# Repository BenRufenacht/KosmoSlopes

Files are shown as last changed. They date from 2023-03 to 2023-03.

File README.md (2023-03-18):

# KosmoSlopes
 Kosmo Version of the Kassutronics Slope Module

 <p align="center">
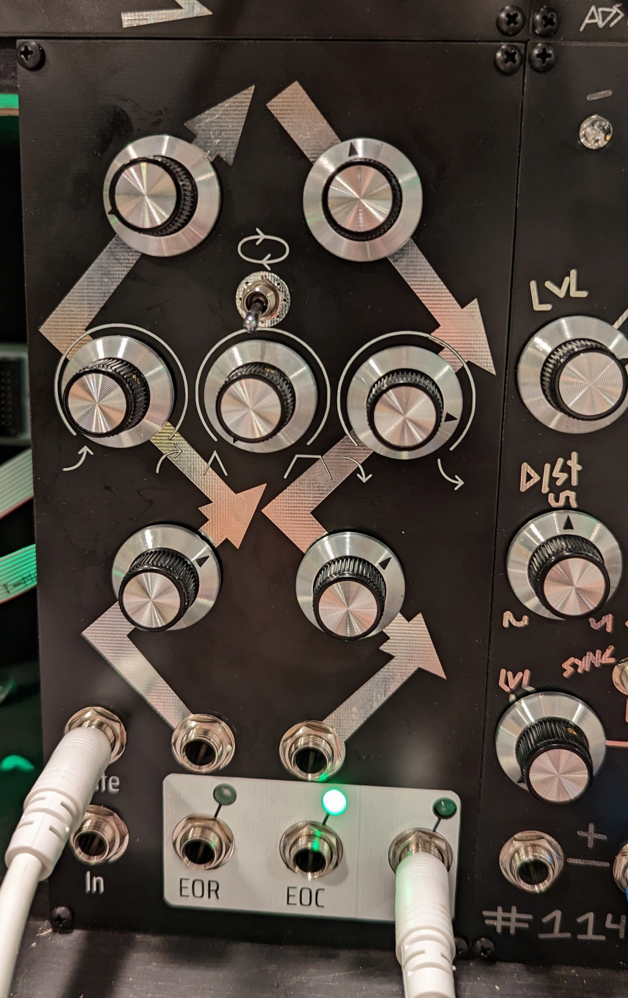
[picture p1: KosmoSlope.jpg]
Kosmo Slope
  
</p>

[Build Docs from Kassutronics](https://github.com/kassu/kassutronics/blob/master/documentation/Slope/Kassutronics_Slope_Build_Docs_2.0B.pdf)

Status:   
February 2023 - First run of manufacturing found some minor mistakes that were fixed, but the updates to the main board have not been tested.

License:  
[CC-BY-SA](https://creativecommons.org/licenses/by-sa/3.0/)

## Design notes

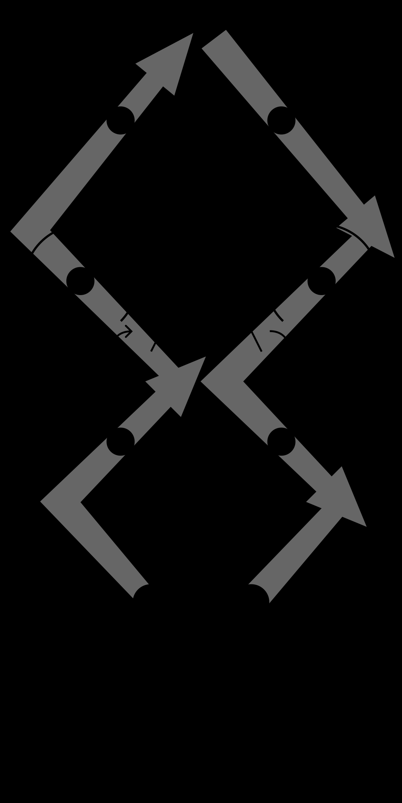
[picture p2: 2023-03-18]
SlopePanelTin.png

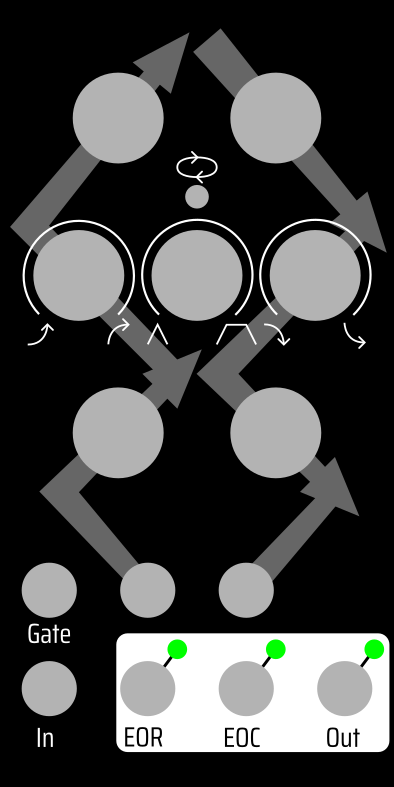
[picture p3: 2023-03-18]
SlopePanelGraphic.png

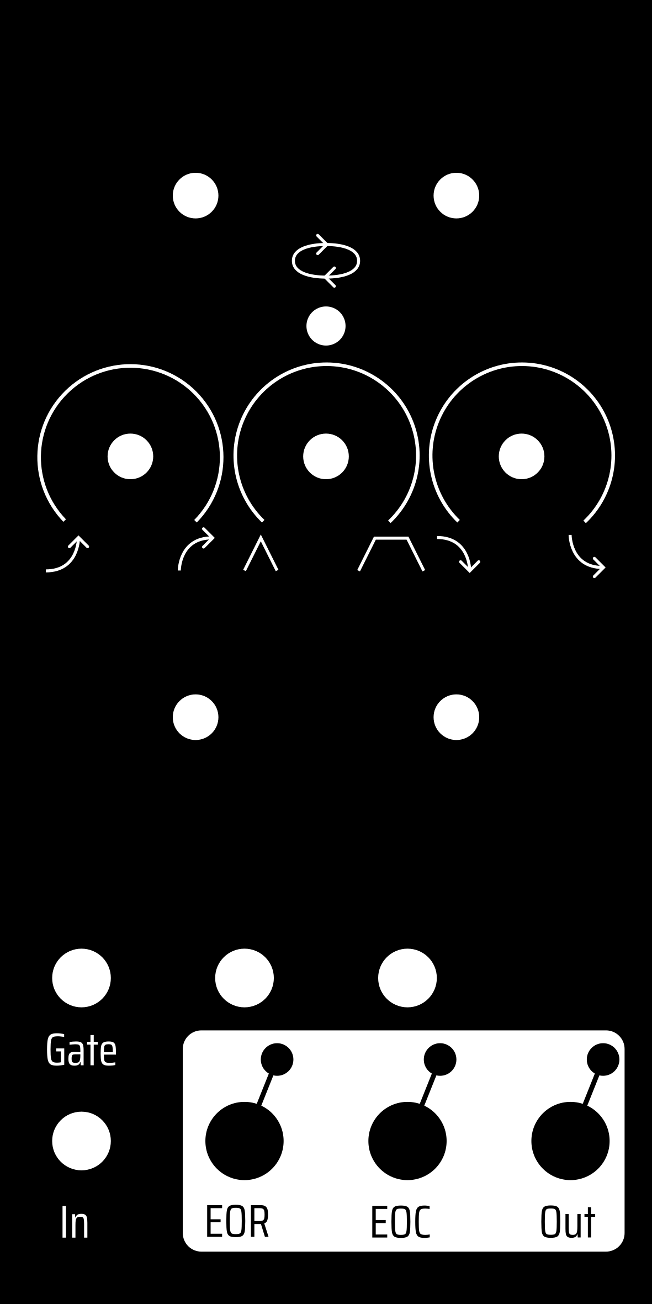
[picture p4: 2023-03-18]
SlopePanelSilk.png

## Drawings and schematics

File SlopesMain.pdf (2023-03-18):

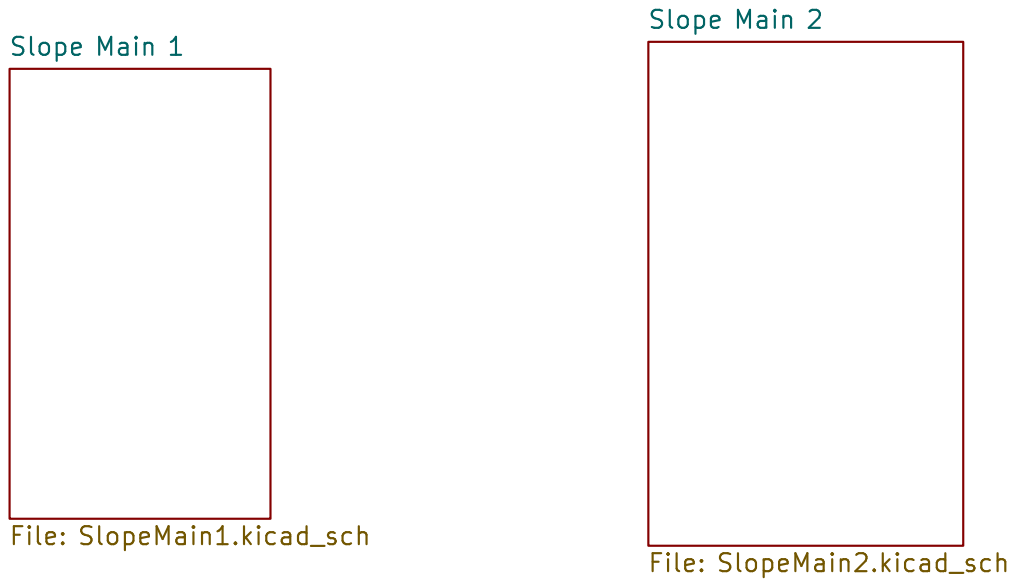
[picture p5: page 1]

File: SlopesMain.kicad_sch Sheet: /
Id: 1/3 Title: Kosmo Slopes

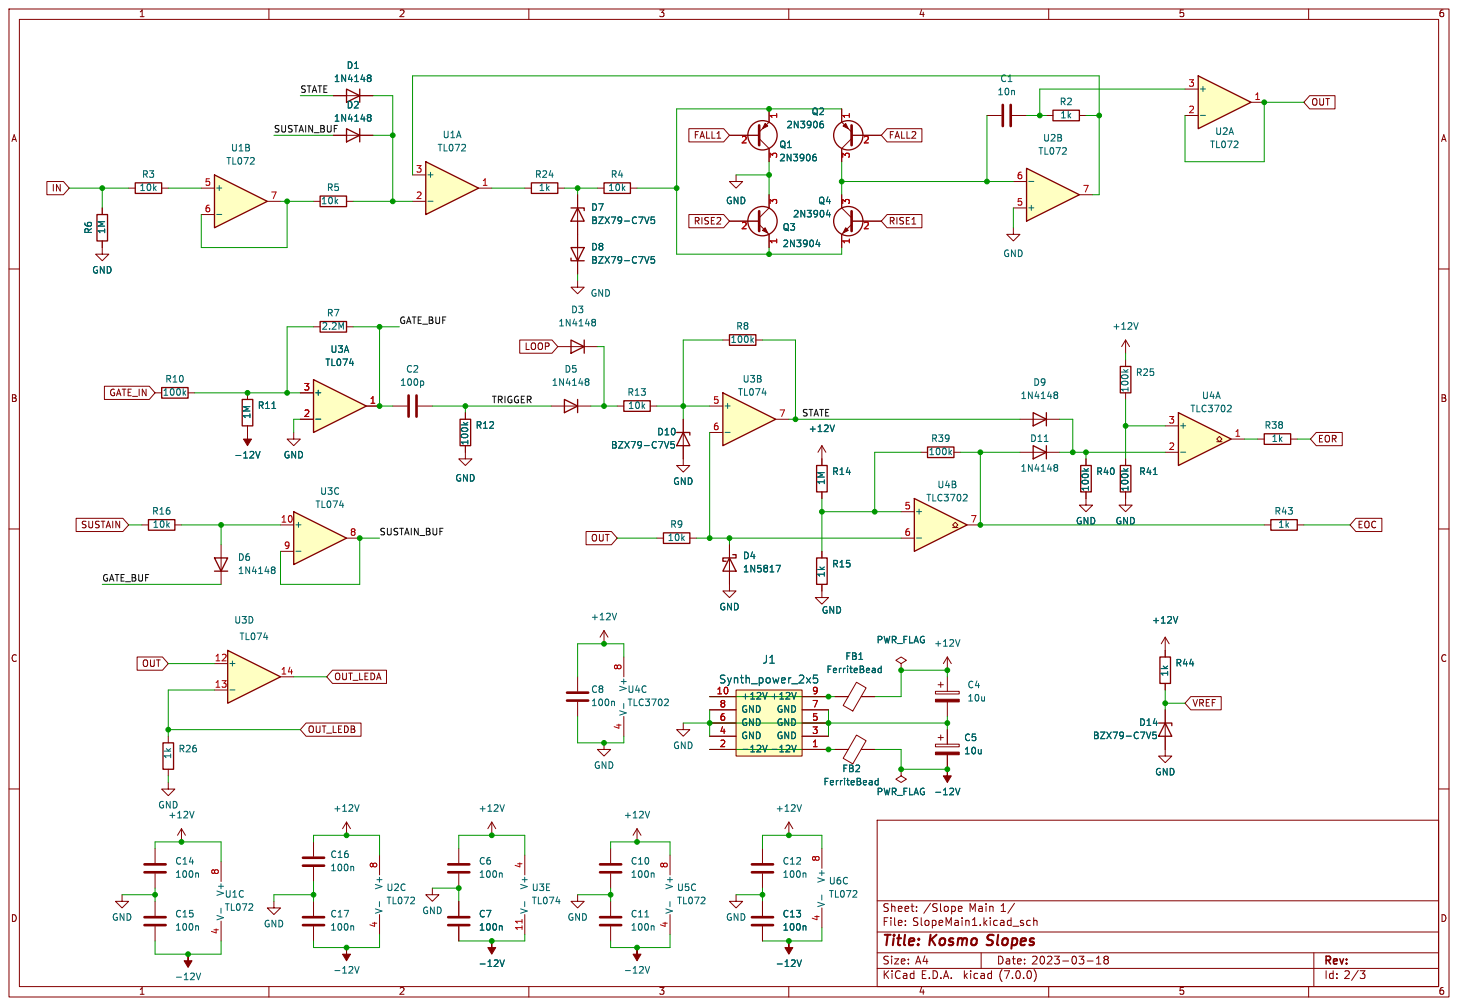
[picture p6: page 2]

Id: 2/3 Title: Kosmo Slopes

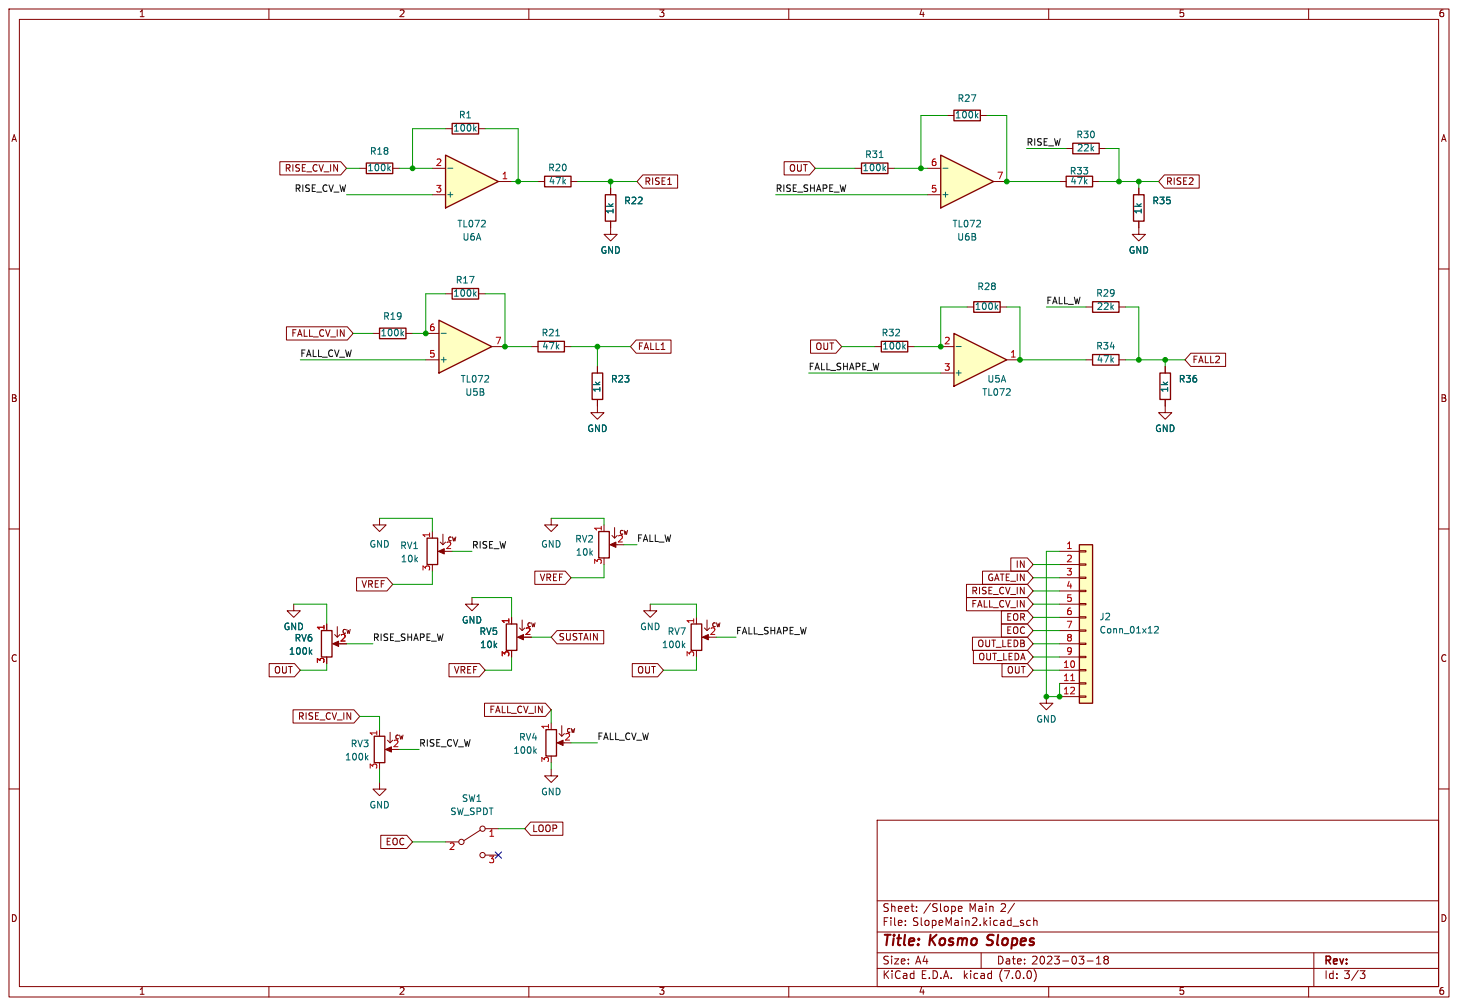
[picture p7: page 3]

Id: 3/3 Title: Kosmo Slopes

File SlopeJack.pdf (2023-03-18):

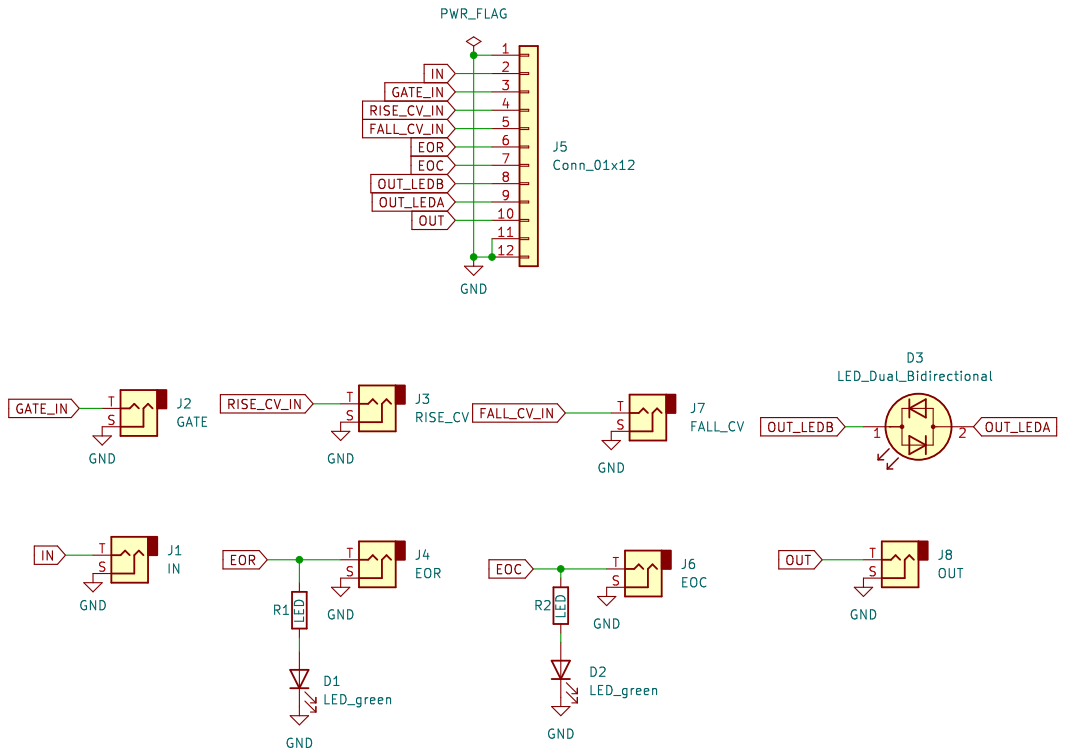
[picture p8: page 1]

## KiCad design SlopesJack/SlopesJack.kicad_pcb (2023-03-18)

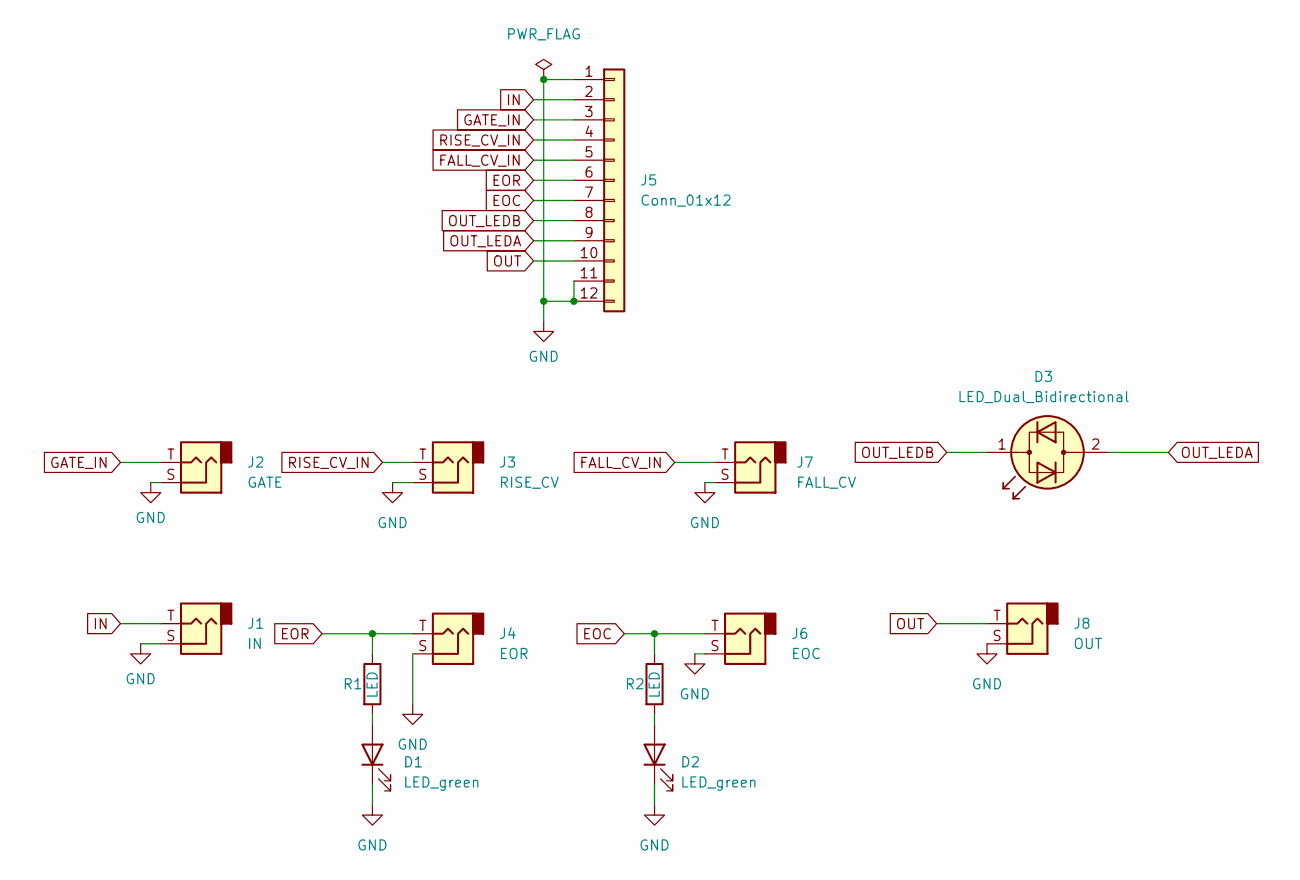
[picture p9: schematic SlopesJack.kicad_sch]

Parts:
D1, D2: LED_green; LED_D5.0mm
D3: LED_Dual_Bidirectional; LED_D5.0mm
J1: IN; Jack_6.35mm_PJ_629HAN_slots
J2: GATE; Jack_6.35mm_PJ_629HAN_slots
J3: RISE_CV; Jack_6.35mm_PJ_629HAN_slots
J4: EOR; Jack_6.35mm_PJ_629HAN_slots
J5: Conn_01x12; PinHeader_1x12_P2.54mm_Vertical
J6: EOC; Jack_6.35mm_PJ_629HAN_slots
J7: FALL_CV; Jack_6.35mm_PJ_629HAN_slots
J8: OUT; Jack_6.35mm_PJ_629HAN_slots
R1, R2: LED; R_Axial_DIN0207_L6.3mm_D2.5mm_P10.16mm_Horizontal

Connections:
EOC: J5.7, J6.T, R2.1
EOR: J4.T, J5.6, R1.1
FALL_CV_IN: J5.5, J7.T
GATE_IN: J2.T, J5.3
GND: D1.1 (K), D2.1 (K), J1.S, J2.S, J3.S, J4.S, J5.1, J5.11, J5.12, J6.S, J7.S, J8.S
IN: J1.T, J5.2
unnamed: D1.2 (A), R1.2
unnamed: D2.2 (A), R2.2
OUT: J5.10, J8.T
OUT_LEDA: D3.2 (AK), J5.9
OUT_LEDB: D3.1 (KA), J5.8
RISE_CV_IN: J3.T, J5.4

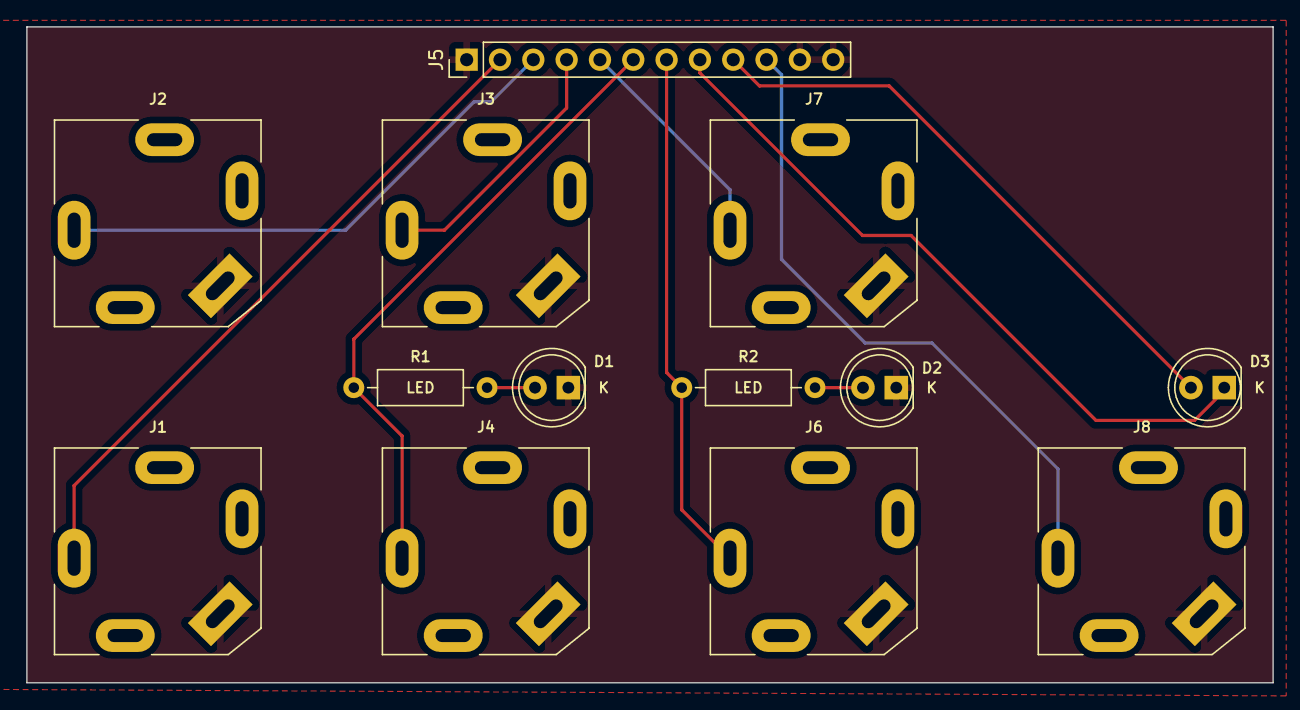
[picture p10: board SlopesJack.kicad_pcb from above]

Board: 2 copper layers, 95.0 x 50.0 mm, 13 parts (0 on the bottom side), 12 nets.

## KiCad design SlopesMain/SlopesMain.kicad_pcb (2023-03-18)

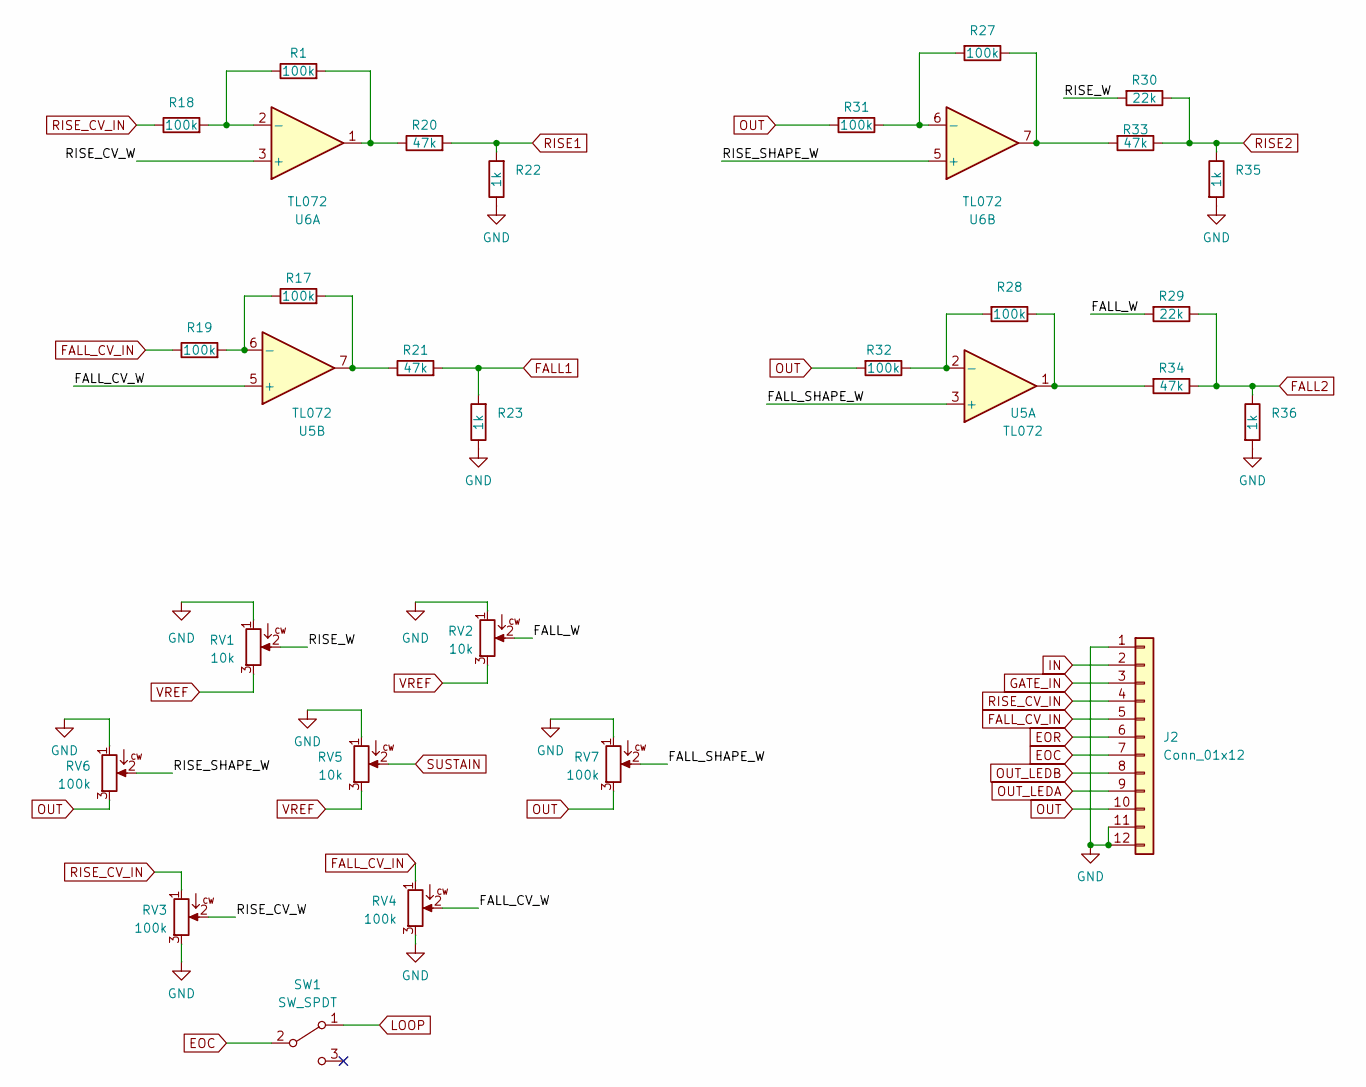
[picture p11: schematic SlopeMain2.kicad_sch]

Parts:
J2: Conn_01x12; PinSocket_1x12_P2.54mm_Vertical
R1, R17, R18, R19, R27, R28, R31, R32: 100k; R_Axial_DIN0207_L6.3mm_D2.5mm_P10.16mm_Horizontal
R20, R21, R33, R34: 47k; R_Axial_DIN0207_L6.3mm_D2.5mm_P10.16mm_Horizontal
R22, R23, R35, R36: 1k; R_Axial_DIN0207_L6.3mm_D2.5mm_P10.16mm_Horizontal
R29, R30: 22k; R_Axial_DIN0207_L6.3mm_D2.5mm_P10.16mm_Horizontal
RV1, RV2, RV5: 10k; Potentiometer_Alpha_RD901F-40-00D_Single_Vertical_centered
RV3, RV4, RV6, RV7: 100k; Potentiometer_Alpha_RD901F-40-00D_Single_Vertical_centered
SW1: SW_SPDT; SPDT-toggle-switch-1M-series
U5, U6: TL072; DIP-8_W7.62mm_Socket_LongPads

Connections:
/Slope Main 2/FALL_CV_W: RV4.2, U5.5 (+)
/Slope Main 2/FALL_SHAPE_W: RV7.2, U5.3 (+)
/Slope Main 2/FALL_W: R29.2, RV2.2
/Slope Main 2/RISE_CV_W: RV3.2, U6.3 (+)
/Slope Main 2/RISE_SHAPE_W: RV6.2, U6.5 (+)
/Slope Main 2/RISE_W: R30.2, RV1.2
EOC: J2.7, SW1.2 (B); also elsewhere on the board
EOR: J2.6; also elsewhere on the board
FALL1: R21.2, R23.2; also elsewhere on the board
FALL2: R29.1, R34.1, R36.1; also elsewhere on the board
FALL_CV_IN: J2.5, R19.1, RV4.1
GATE_IN: J2.3; also elsewhere on the board
GND: J2.1, J2.11, J2.12, R22.1, R23.1, R35.2, R36.2, RV1.1, RV2.1, RV3.3, RV4.3, RV5.1, RV6.1, RV7.1; also elsewhere on the board
IN: J2.2; also elsewhere on the board
LOOP: SW1.1 (A); also elsewhere on the board
unnamed: R1.2, R20.1, U6.1
unnamed: R17.2, R21.1, U5.7
unnamed: R27.1, R33.2, U6.7
unnamed: R28.1, R34.2, U5.1
unnamed: R28.2, R32.1, U5.2 (-)
unnamed: R17.1, R19.2, U5.6 (-)
unnamed: R1.1, R18.2, U6.2 (-)
unnamed: R27.2, R31.1, U6.6 (-)
OUT: J2.10, R31.2, R32.2, RV6.3, RV7.3; also elsewhere on the board
OUT_LEDA: J2.9; also elsewhere on the board
OUT_LEDB: J2.8; also elsewhere on the board
RISE1: R20.2, R22.2; also elsewhere on the board
RISE2: R30.1, R33.1, R35.1; also elsewhere on the board
RISE_CV_IN: J2.4, R18.1, RV3.1
SUSTAIN: RV5.2; also elsewhere on the board
VREF: RV1.3, RV2.3, RV5.3; also elsewhere on the board

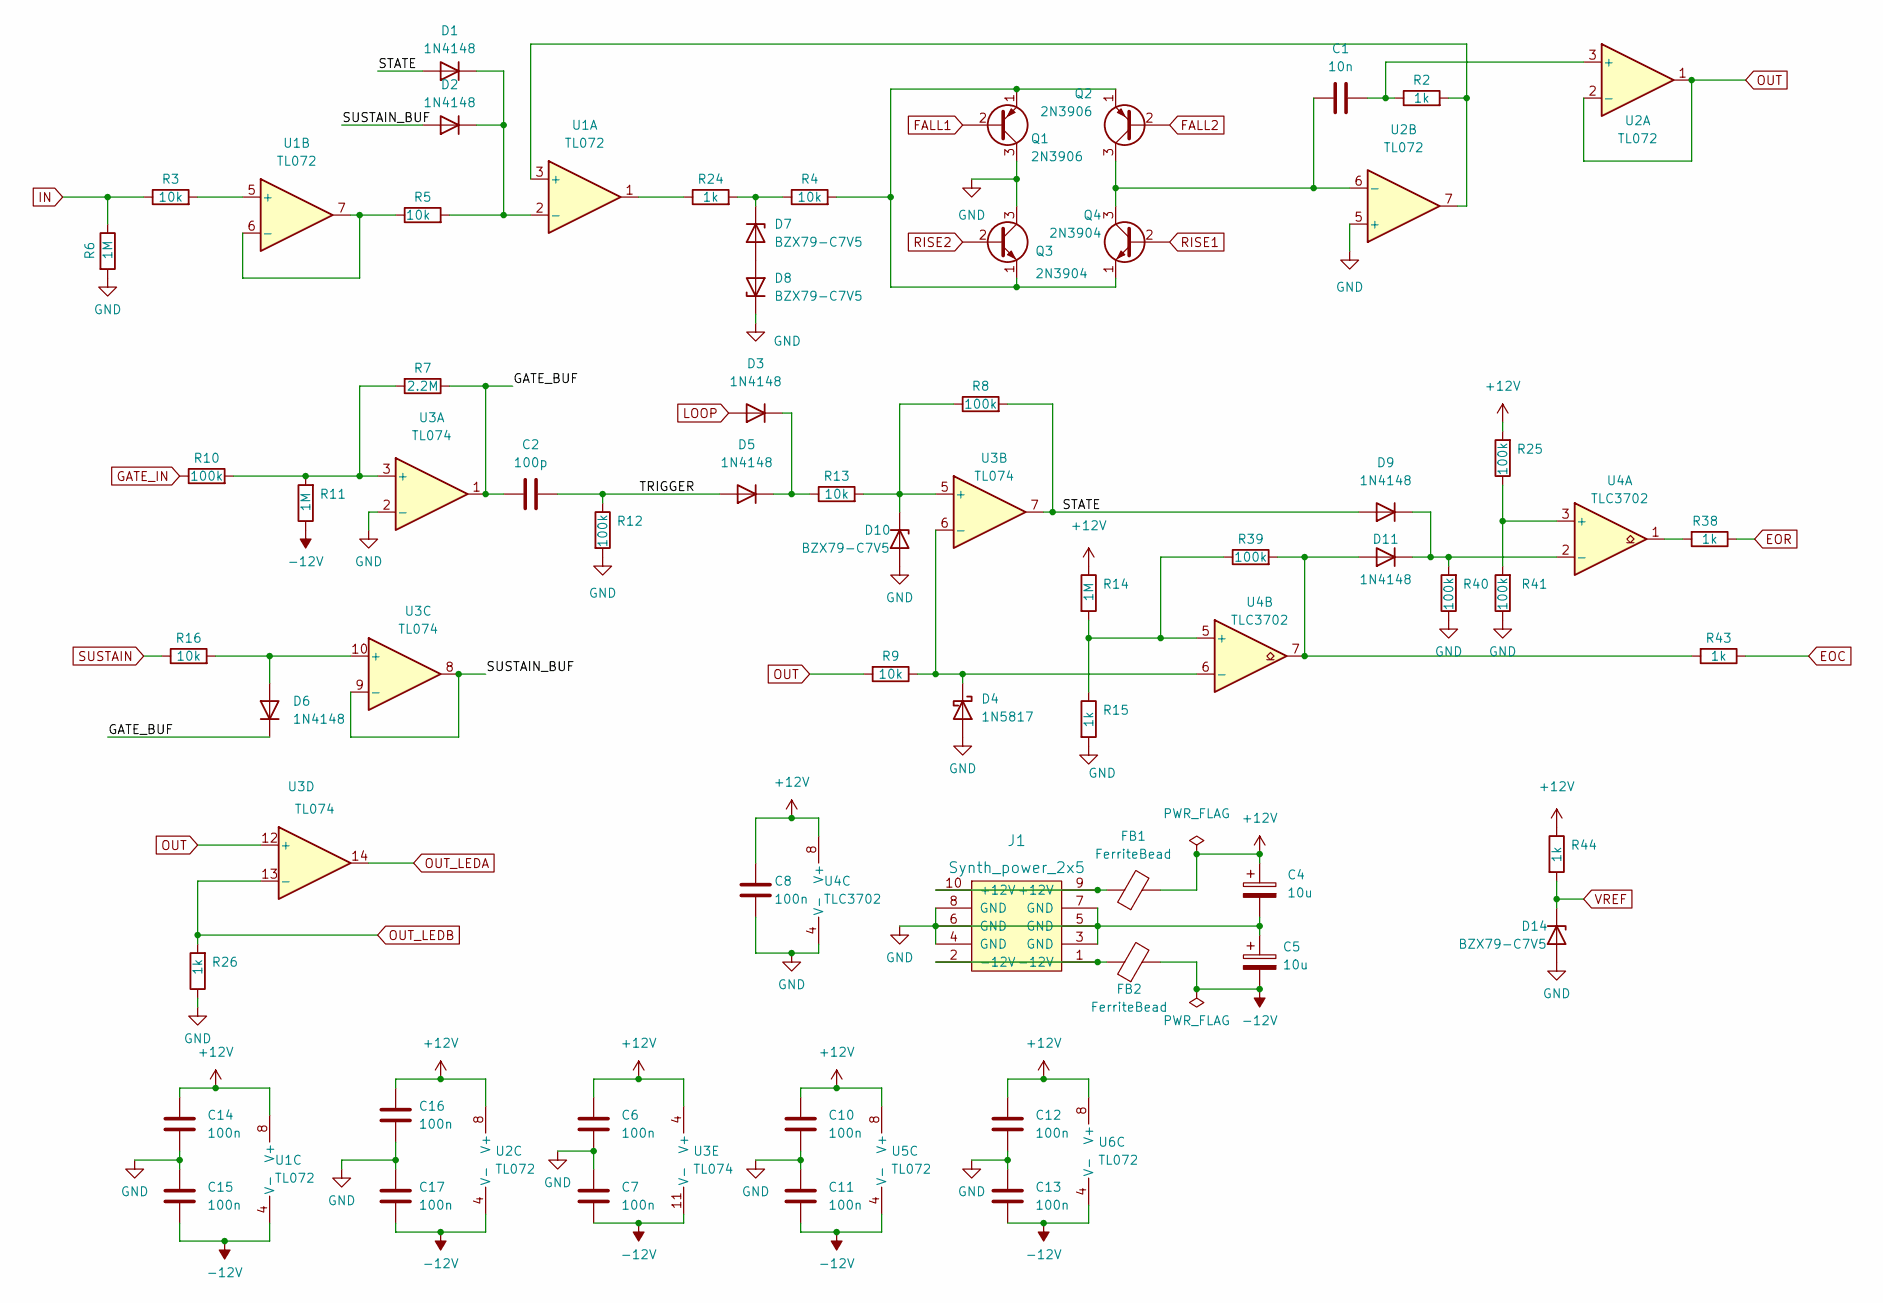
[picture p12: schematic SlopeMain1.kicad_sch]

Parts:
C1: 10n; C_Rect_L7.2mm_W2.5mm_P5.00mm_FKS2_FKP2_MKS2_MKP2
C2: 100p; C_Rect_L7.2mm_W2.5mm_P5.00mm_FKS2_FKP2_MKS2_MKP2
C4, C5: 10u; CP_Radial_D6.3mm_P2.50mm
C6, C7, C8, C10, C11, C12, C13, C14, C15, C16, C17: 100n; C_Rect_L7.2mm_W2.5mm_P5.00mm_FKS2_FKP2_MKS2_MKP2
D1, D2, D3, D5, D6, D9, D11: 1N4148; D_DO-35_SOD27_P7.62mm_Horizontal
D4: 1N5817; D_DO-41_SOD81_P10.16mm_Horizontal
D7, D8, D10, D14: BZX79-C7V5; D_DO-41_SOD81_P10.16mm_Horizontal
FB1, FB2: FerriteBead; L_Axial_L5.0mm_D3.6mm_P10.00mm_Horizontal_Murata_BL01RN1A2A2
J1: Synth_power_2x5; Power_Header
Q1, Q2: 2N3906; TO-92_Inline_Wide
Q3, Q4: 2N3904; TO-92_Inline_Wide
R2, R15, R24, R26, R38, R43, R44: 1k; R_Axial_DIN0207_L6.3mm_D2.5mm_P10.16mm_Horizontal
R3, R4, R5, R9, R13, R16: 10k; R_Axial_DIN0207_L6.3mm_D2.5mm_P10.16mm_Horizontal
R6, R11, R14: 1M; R_Axial_DIN0207_L6.3mm_D2.5mm_P10.16mm_Horizontal
R7: 2.2M; R_Axial_DIN0207_L6.3mm_D2.5mm_P10.16mm_Horizontal
R8, R10, R12, R25, R39, R40, R41: 100k; R_Axial_DIN0207_L6.3mm_D2.5mm_P10.16mm_Horizontal
U1, U2, U5, U6: TL072; DIP-8_W7.62mm_Socket_LongPads
U3: TL074; DIP-14_W7.62mm_Socket_LongPads
U4: TLC3702; DIP-8_W7.62mm_Socket_LongPads

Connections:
+12V: C4.1, C6.1, C8.1, C10.1, C12.1, C14.1, C16.1, FB1.2, R14.1, R25.2, R44.1, U1.8 (V+), U2.8 (V+), U3.4 (V+), U4.8 (V+), U5.8 (V+), U6.8 (V+)
-12V: C5.2, C7.2, C11.2, C13.2, C15.2, C17.2, FB2.2, R11.1, U1.4 (V-), U2.4 (V-), U3.11 (V-), U5.4 (V-), U6.4 (V-)
/Slope Main 1/GATE_BUF: C2.1, D6.1 (K), R7.1, U3.1
/Slope Main 1/STATE: D1.2 (A), D9.2 (A), R8.2, U3.7
/Slope Main 1/SUSTAIN_BUF: D2.2 (A), U3.8, U3.9 (-)
/Slope Main 1/TRIGGER: C2.2, D5.2 (A), R12.1
EOC: R43.1; also elsewhere on the board
EOR: R38.1; also elsewhere on the board
FALL1: Q1.2 (B); also elsewhere on the board
FALL2: Q2.2 (B); also elsewhere on the board
GATE_IN: R10.1; also elsewhere on the board
GND: C4.2, C5.1, C6.2, C7.1, C8.2, C10.2, C11.1, C12.2, C13.1, C14.2, C15.1, C16.2, C17.1, D4.2 (A), D8.1 (K), D10.2 (A), D14.2 (A), J1.3 (GND), J1.4 (GND), J1.5 (GND), J1.6 (GND), J1.7 (GND), J1.8 (GND), Q1.3 (C), Q3.3 (C), R6.2, R12.2, R15.2, R26.1, R40.1, R41.1, U2.5 (+), U3.2 (-), U4.4 (V-); also elsewhere on the board
IN: R3.1, R6.1; also elsewhere on the board
LOOP: D3.2 (A); also elsewhere on the board
unnamed: D1.1 (K), D2.1 (K), R5.2, U1.2 (-)
unnamed: D3.1 (K), D5.1 (K), R13.1
unnamed: D4.1 (K), R9.1, U3.6 (-), U4.6 (_)
unnamed: D6.2 (A), R16.2, U3.10 (+)
unnamed: D7.2 (A), D8.2 (A)
unnamed: D7.1 (K), R4.1, R24.2
unnamed: D10.1 (K), R8.1, R13.2, U3.5 (+)
unnamed: D11.2 (A), R39.2, R43.2, U4.7
unnamed: D9.1 (K), D11.1 (K), R40.2, U4.2 (-)
unnamed: FB1.1, J1.9 (+12V), J1.10 (+12V)
unnamed: FB2.1, J1.1 (-12V), J1.2 (-12V)
unnamed: Q1.1 (E), Q2.1 (E), Q3.1 (E), Q4.1 (E), R4.2
unnamed: C1.1, Q2.3 (C), Q4.3 (C), U2.6 (-)
unnamed: R24.1, U1.1
unnamed: R38.2, U4.1
unnamed: R2.2, U1.3 (+), U2.7
unnamed: R3.2, U1.5 (+)
unnamed: R5.1, U1.6 (-), U1.7
unnamed: C1.2, R2.1, U2.3 (+)
unnamed: R7.2, R10.2, R11.2, U3.3 (+)
unnamed: R25.1, R41.2, U4.3 (+)
unnamed: R14.2, R15.1, R39.1, U4.5 (+)
OUT: R9.2, U2.1, U2.2 (-), U3.12 (+); also elsewhere on the board
OUT_LEDA: U3.14; also elsewhere on the board
OUT_LEDB: R26.2, U3.13 (-); also elsewhere on the board
RISE1: Q4.2 (B); also elsewhere on the board
RISE2: Q3.2 (B); also elsewhere on the board
SUSTAIN: R16.1; also elsewhere on the board
VREF: D14.1 (K), R44.2; also elsewhere on the board

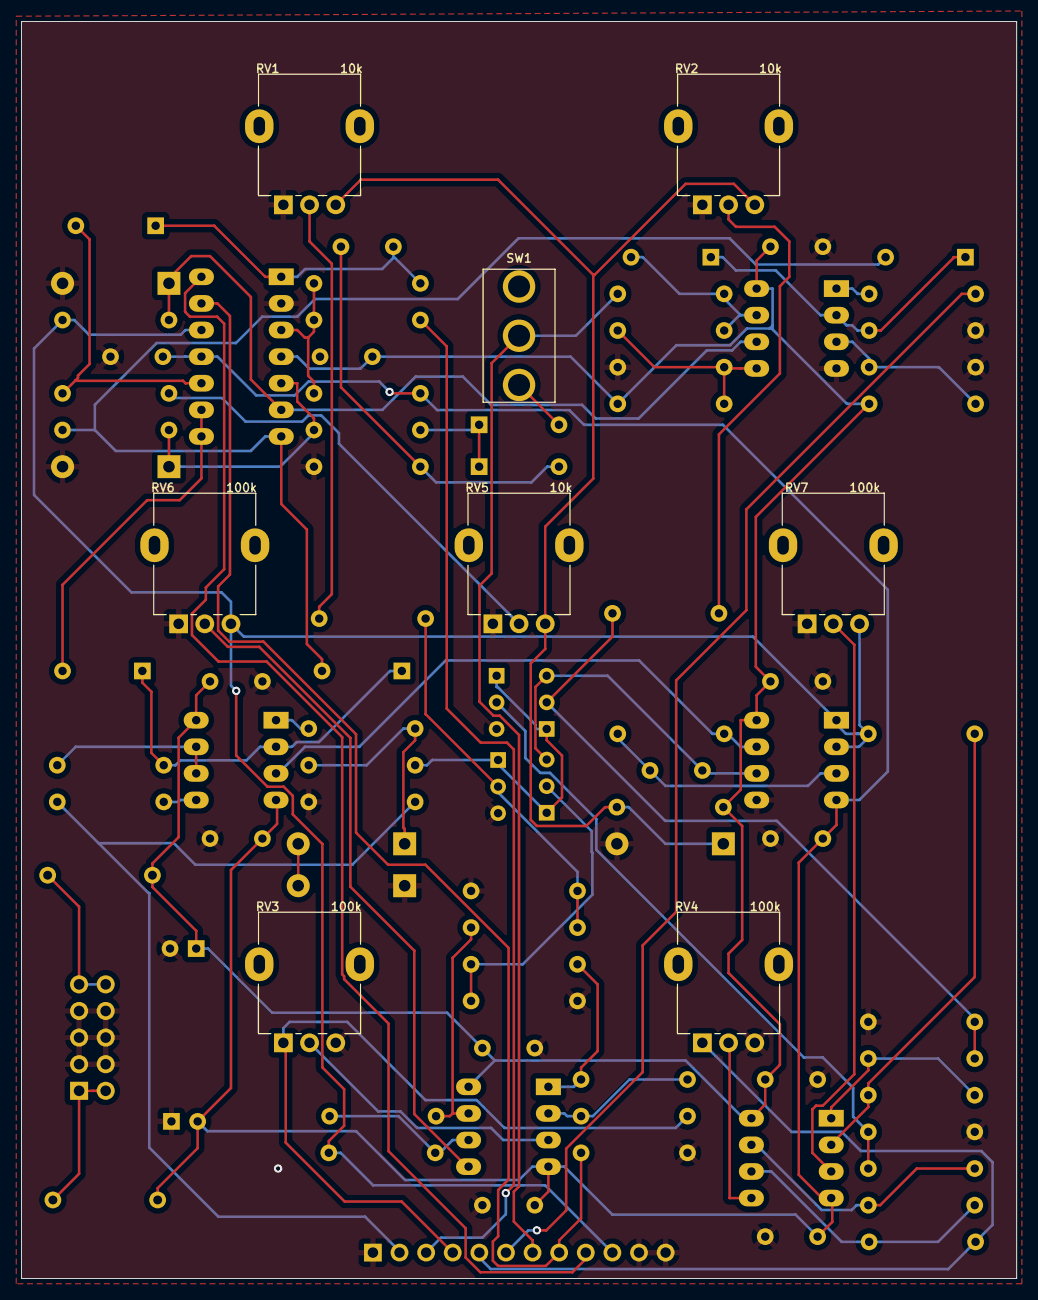
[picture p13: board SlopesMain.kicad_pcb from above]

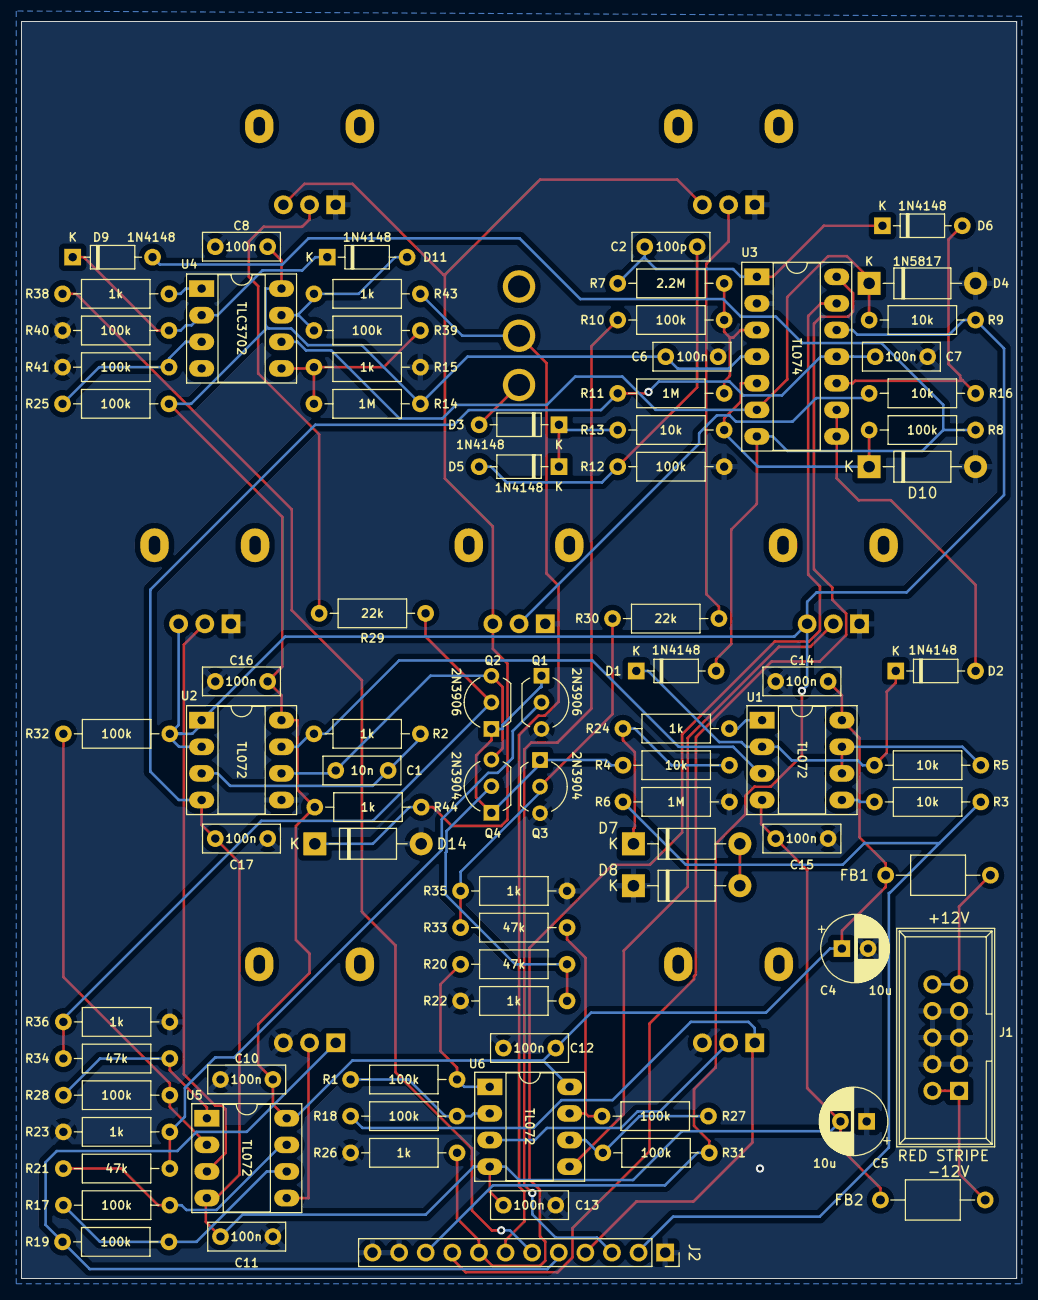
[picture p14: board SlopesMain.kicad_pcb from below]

Board: 2 copper layers, 95.0 x 120.0 mm, 91 parts (83 on the bottom side), 59 nets.
